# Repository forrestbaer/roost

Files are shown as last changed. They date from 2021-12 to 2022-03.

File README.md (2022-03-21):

## Roost keyboard

Based off the Sweep v2.1, added 2mm or so horizontal space, added another set of keys and slots for a fat power switch. Moved battery connectors to the board, moved reset switch so it's easier to get to without being in the way. Larger holes are for mounting these: Mouser part: 575-7305015154727100 for pluggable switches.

Recently added v2 gerbers which use normal Kalih choc hot pluggable sockets as they're MUCH easier and more reliable to solder than the plugs.. Also did a few routing changes but it's otherwise the same board, same config.

Feel free to copy and modify..

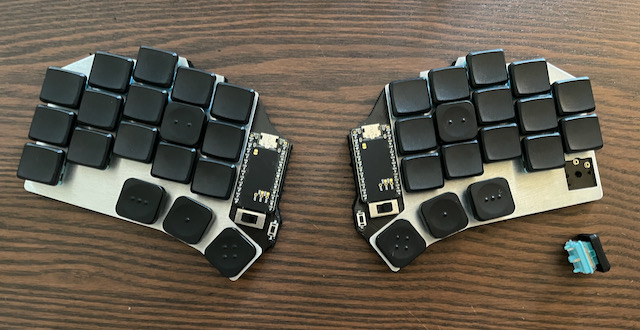
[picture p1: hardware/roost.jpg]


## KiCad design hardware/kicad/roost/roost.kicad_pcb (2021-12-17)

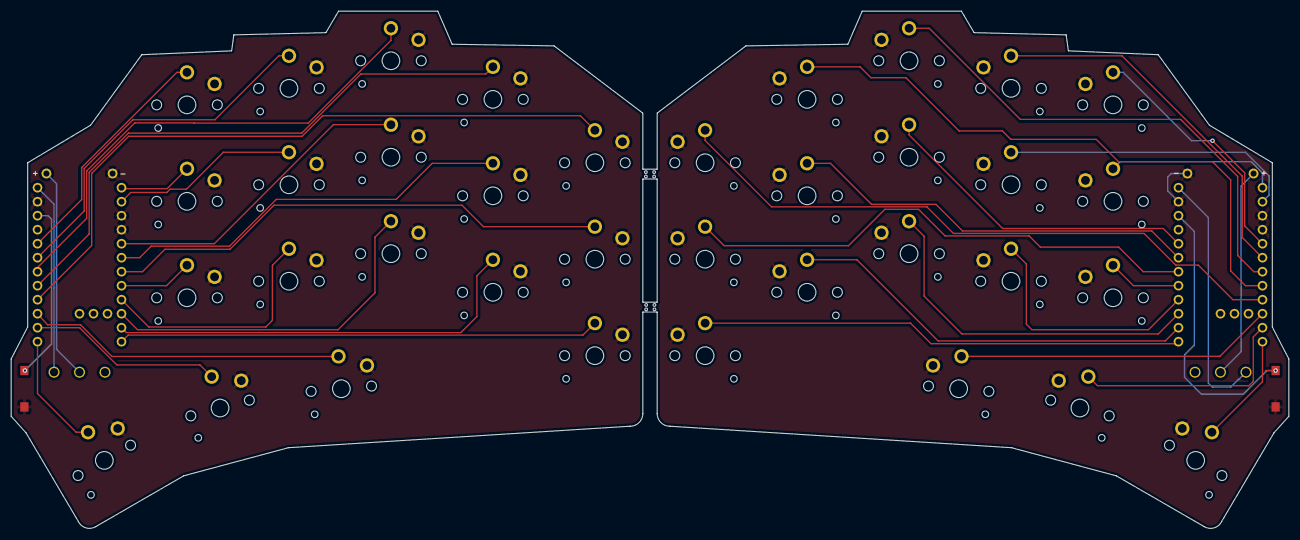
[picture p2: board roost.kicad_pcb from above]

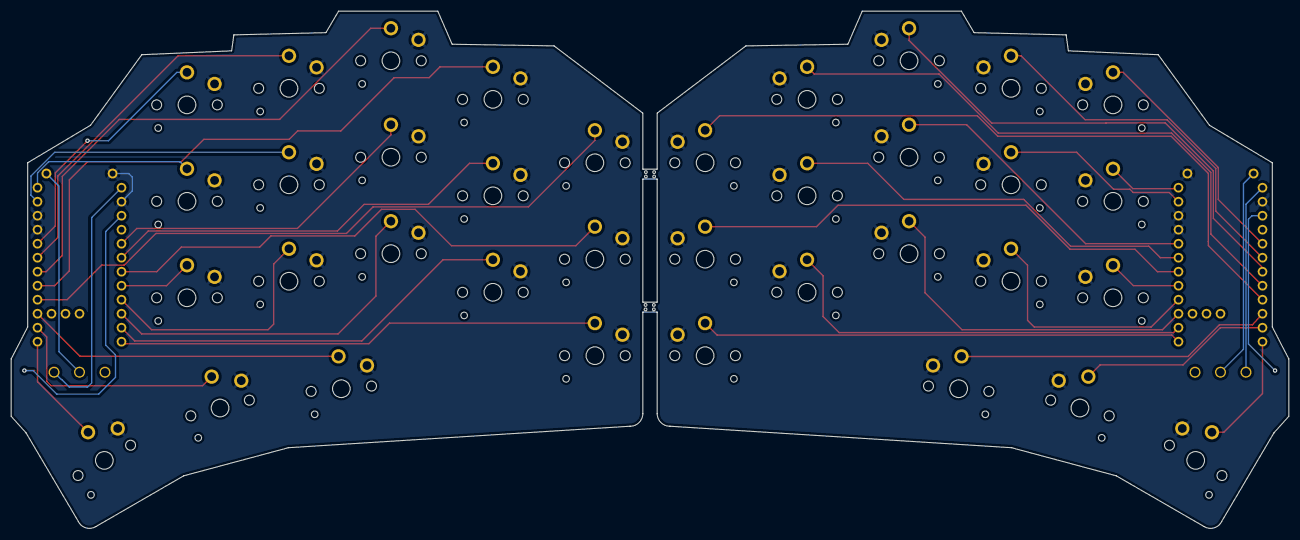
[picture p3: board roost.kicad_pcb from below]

Board: 2 copper layers, 231.8 x 93.8 mm, 48 parts (22 on the bottom side), 42 nets.

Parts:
+: MountingHole_Pad; battery hole
+#2: MountingHole_Pad; battery hole
-: MountingHole_Pad; battery hole
-#2: MountingHole_Pad; battery hole
RSW1, RSW2: SW_Push; SW_SPST_B3U-1000P
SW1, SW2, SW3, SW4, SW5, SW6, SW7, SW8, SW9, SW10, SW11, SW12, SW13, SW14, SW15, SW16, SW17, SW18: SW_Push; SW_Kailh_Choc_V1_1.00u
SW_POWER1: SW_SPDT; bigswitch
SW_POWERR1: SW_SPDT; bigswitch
SWr1, SWr2, SWr3, SWr4, SWr5, SWr6, SWr7, SWr8, SWr9, SWr10, SWr11, SWr12, SWr13, SWr14, SWr15, SWr16, SWr17, SWr18: SW_Push; SW_Kailh_Choc_V1_1.00u
U1, U2: nice_nano
mouse-bite-2mm-slot, mouse-bite-2mm-slot#2: VAL**; mouse-bite-2mm-slot-with-space-for-track

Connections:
BT+: +#2.1, SW_POWER1.2
BT+_r: +.1, SW_POWERR1.2
Switch1: SW1.1, U1.9
Switch1_r: SWr1.1, U2.16
Switch2: SW2.1, U1.8
Switch2_r: SWr2.1, U2.17
Switch3: SW3.1, U1.7
Switch3_r: SWr3.1, U2.18
Switch4: SW4.1, U1.6
Switch4_r: SWr4.1, U2.19
Switch5: SW5.1, U1.5
Switch5_r: SWr5.1, U2.20
Switch6: SW6.1, U1.18
Switch6_r: SWr6.1, U2.7
Switch7: SW7.1, U1.19
Switch7_r: SWr7.1, U2.6
Switch8: SW8.1, U1.20
Switch8_r: SWr8.1, U2.5
Switch9: SW9.1, U1.2
Switch9_r: SWr9.1, U2.2
Switch10: SW10.1, U1.1
Switch10_r: SWr10.1, U2.1
Switch11: SW11.1, U1.13
Switch11_r: SWr11.1, U2.12
Switch12: SW12.1, U1.14
Switch12_r: SWr12.1, U2.11
Switch13: SW13.1, U1.15
Switch13_r: SWr13.1, U2.10
Switch14: SW14.1, U1.16
Switch14_r: SWr14.1, U2.9
Switch15: SW15.1, U1.17
Switch15_r: SWr15.1, U2.8
Switch16: SW16.1, U1.10
Switch16_r: SWr16.1, U2.15
Switch17: SW17.1, U1.11
Switch17_r: SWr17.1, U2.14
Switch18: SW18.1, U1.12
Switch18_r: SWr18.1, U2.13
gnd: -.1, -#2.1, RSW1.1, RSW2.1, SW1.2, SW2.2, SW3.2, SW4.2, SW5.2, SW6.2, SW7.2, SW8.2, SW9.2, SW10.2, SW11.2, SW12.2, SW13.2, SW14.2, SW15.2, SW16.2, SW17.2, SW18.2, SWr1.2, SWr2.2, SWr3.2, SWr4.2, SWr5.2, SWr6.2, SWr7.2, SWr8.2, SWr9.2, SWr10.2, SWr11.2, SWr12.2, SWr13.2, SWr14.2, SWr15.2, SWr16.2, SWr17.2, SWr18.2, U1.3, U1.4, U1.23, U2.3, U2.4, U2.23
raw: SW_POWER1.3, SW_POWERR1.3, U1.24, U2.24
reset: RSW1.2, U1.22
reset_r: RSW2.2, U2.22

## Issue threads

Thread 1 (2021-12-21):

arduino pro micro

rnyPlanet, 2021-12-21:
can arduino pro micro be used instead of nrf micro?) (litter for such a question - I have little knowledge)

forrestbaer, 2021-12-21:
I suppose anything compatible with the cradio zmk keymap would work, you would need bluetooth as the boards do not have a way to communicate with eachother otherwise. I have only used this with the nice!nano 2.

Closed 2021-12-21.

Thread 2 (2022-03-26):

Reversible PCB

andrewneyman, 2022-03-26:
Not really an issue, just wondering if this is a planned feature

forrestbaer, 2022-03-26:
Nope sorry, I built a few of these and am happy with them for now, going to move on to other projects.

Closed 2022-03-26.

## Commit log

2021-12-17 adding kicad files
    [roost.kicad_pcb, roost.kicad_sch, roost.sch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]
2022-01-17 added v2 first draft
    [roost_v2-brd.dxf, roost_v2.kicad_pcb, roost_v2.kicad_sch]
2022-01-29 Adding a better v2 with option for mountable sockets which seem to work a lot better and are easier to use without accidentally getting solder in the mount holes
    [roost_leftv2.kicad_pcb, roost_rightv2.kicad_pcb, roost_v2-brd.dxf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]
2022-02-05 added version 2 with standard kailh choc hotswap sockets which are much more reliable and easy to solder than the plugs
    [roostv2_bottom.kicad_pcb]
